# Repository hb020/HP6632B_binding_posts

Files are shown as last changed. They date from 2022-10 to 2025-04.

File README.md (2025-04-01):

HP 66332A and HP 6632B-6634B Frontpanel Binding Post PCB
===================
This repository contains the schematics for a PCB to mount frontpanel binding post on an HP 6632B (and siblings) power supply. It is an adaption of the original A4 PCB used in option #020 units.

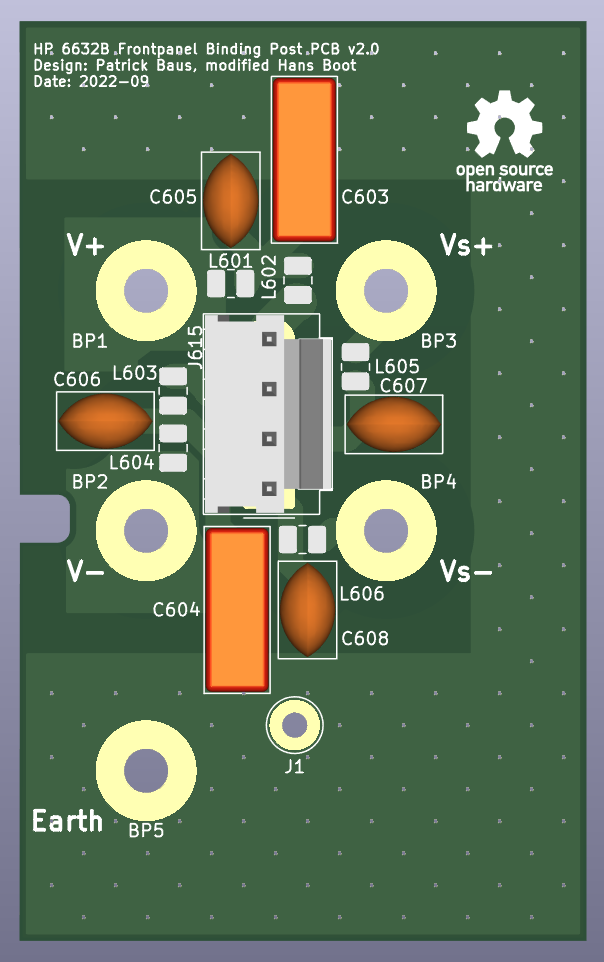
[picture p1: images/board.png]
Current driver circuit board


In contrast to the original option #20 PCB, this board breaks out the sense connections as well and also the chassis ground. This makes connecting multiple HP 663xB in parallel possible. On the downside, this requires connecting the sense pins externally.   

The components chosen allow the board to be used on all variants of the HP 663xB family - even the 100 V 6634B. A variety of different binding posts can be used. There are HP/Agilent versions available on Ebay. Examples:
- Pomona 4243-0 ([Digikey](https://www.digikey.de/en/products/detail/pomona-electronics/4243-0/604321)) and 3760-5 ([Digikey](https://www.digikey.de/en/products/detail/pomona-electronics/3760-5/736554)).
- EZ-Hook 9406 ([Digikey](https://www.digikey.fr/en/products/detail/e-z-hook/9406/574036)) (only to be found in red and black as a set or individually under the name EZ-Hook 9280BLK or 9280RED)

The final result looks like this:
HP 66332A with binding posts

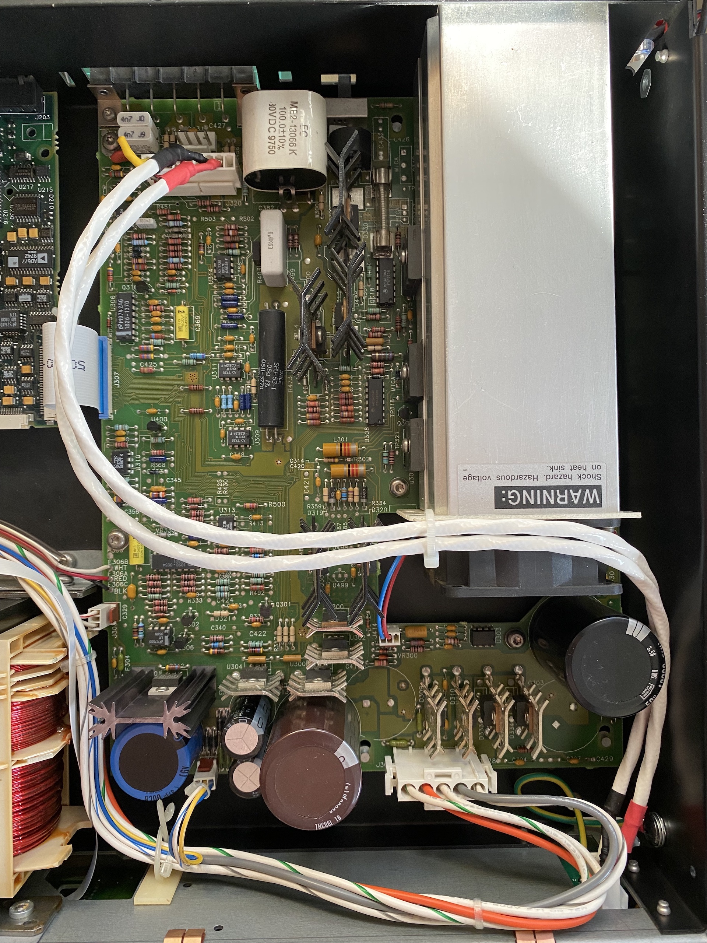
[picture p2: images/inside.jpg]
HP 66332A inside


The following changes were made to Patrick Baus's original version:

- the terminals are moved around to match a more standard layout.
- added documentation about the connectivity to the main board.
- the wire connections are moved to better align with the hole in the chassis behind the posts.
- the slot in the PCB for the front panel fixation screw is widened a bit to allow more freedom.
- newer KiCad version (6.0).
- added a FreeCAD model.
- uses a 3D printed [Front Terminal Adapter](freecad/Front_Terminal_Adapter.stl) (also see below) for more rigidity.

About
-----
The root folder contains the KiCAD files.

The gerber files can be found in the [/gerber](gerber/) folder.

A 3D model from FreeCAD can be found in the [/freecad](freecad/) folder. That model was used to determine the placement of the connector and the ground wire.

Labels for a Dymo printer can be found in the [/labels](labels/) folder.

Test scripts (via Prologix USB-GPIB) can be found in the [/testscripts](testscripts/) folder.

Related Repositories and info
-----------------------------

See the following repositories for more information

KiCAD schematic libraries: https://github.com/PatrickBaus/KiCad-libraries

A "HP 66xxA 65xxA PSU Front Panel Binding Post Adapter" plate from [NearFarMedia](https://www.thingiverse.com/thing:4299873) is recommended. It is also [included in the FreeCad file](freecad/Front_Terminal_Adapter.stl). The slots for the binding posts might be a bit tighter, but it works superbly.

I'd also recommend to look at [Barbouri's efforts](https://www.barbouri.com/2021/04/23/hewlett-packard-agilent-6632b-upgrade/) for his upgrade.

You may want to combine this with the [option 760 relay board](https://github.com/hb020/HP6632B_relay_board).

License
-------

This work is released under the Cern OHL v.1.2
See www.ohwr.org/licenses/cern-ohl/v1.2 or the included LICENSE file for more information.

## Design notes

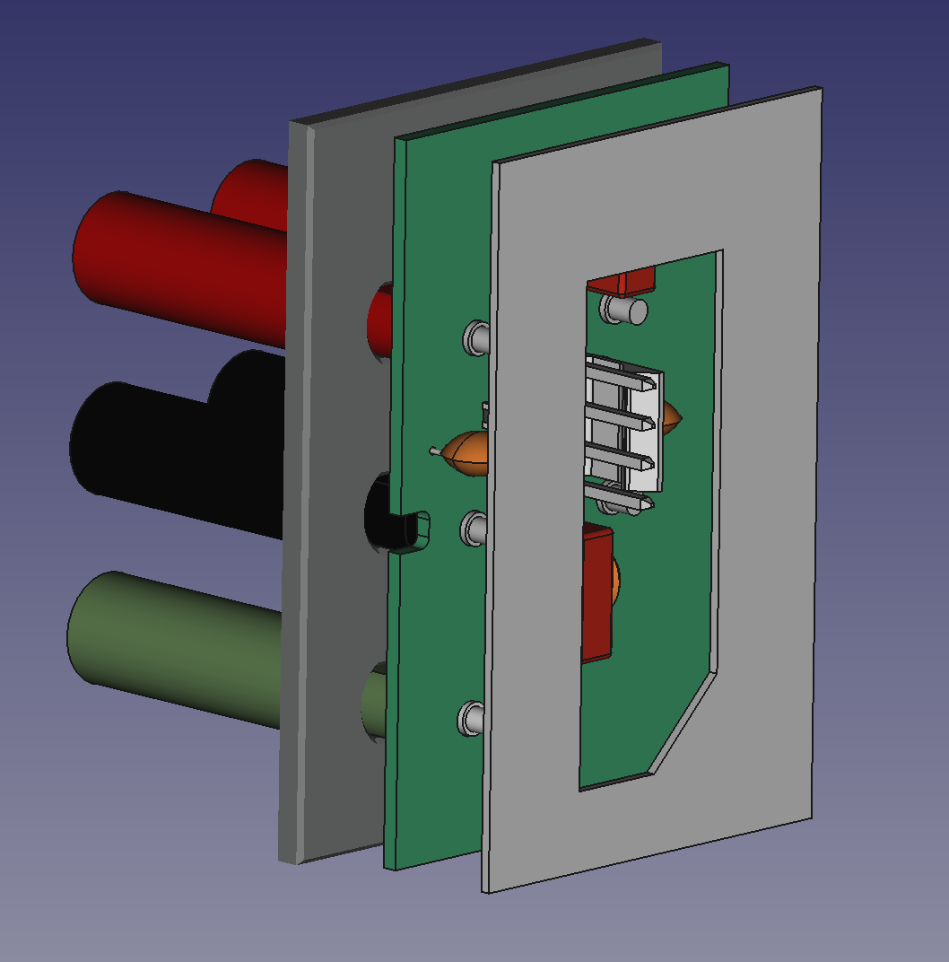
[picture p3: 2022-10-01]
images/3d.png

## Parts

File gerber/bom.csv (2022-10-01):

Designator | Footprint | Quantity | Value | LCSC Part #
BP1, BP2, BP3, BP4, BP5 | MountingHole_3.5mm_Pad | 5 | Conn_01x01
C603, C604 | C_Rect_L13.0mm_W5.0mm_P10.00mm_FKS3_FKP3_MKS4 | 2 | 4.7n
C605, C606, C607, C608 | C_Disc_D7.5mm_W4.4mm_P5.00mm | 4 | 220p
J1 | TestPoint_THTPad_D4.0mm_Drill2.0mm | 1 | Conn_01x01
J615 | Molex_KK-396_A-41791-0004_1x04_P3.96mm_Vertical | 1 | Conn_01x04_Male
L601, L602, L603, L604, L605, L606 | L_1008_2520Metric_Pad1.43x2.20mm_HandSolder | 6 | 150n
LOGO1 | OSHW-Logo_7.5x8mm_SilkScreen | 1 | Logo_Open_Hardware_Small

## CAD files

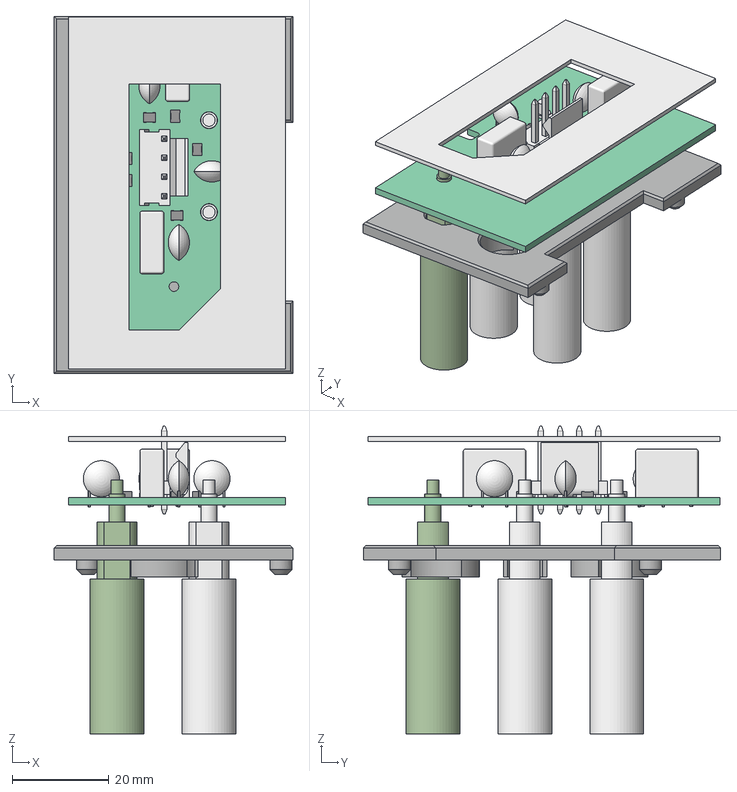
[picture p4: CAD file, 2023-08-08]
freecad/combined.FCStd
49.5 x 74.0 x 63.8 mm
9280_GND
Pcb_361c
C604_C_Rect_L130mm_W50mm_P1000mm_FKS3_FKP3_MKS4_00005f239962
C605_C_Disc_D75mm_W44mm_P500mm_00005f239977
L601_L_1008_2520Metric_00005f2399cf
L603_L_1008_2520Metric_00005f2399f1
L606_L_1008_2520Metric_00005f23d51d
C607_C_Disc_D75mm_W44mm_P500mm_00005f23e080
C608_C_Disc_D75mm_W44mm_P500mm_00005f23e095
L602_L_1008_2520Metric_00005f241a9f
L604_L_1008_2520Metric_00005f2428f3
L605_L_1008_2520Metric_00005f242ef0
C603_C_Rect_L130mm_W50mm_P1000mm_FKS3_FKP3_MKS4_00005f247355
J615_1_00005f3145fd[2]
C606_C_Disc_D75mm_W44mm_P500mm_00005f315ffa
Back_metal_cutout
Front_Terminal_Adapter

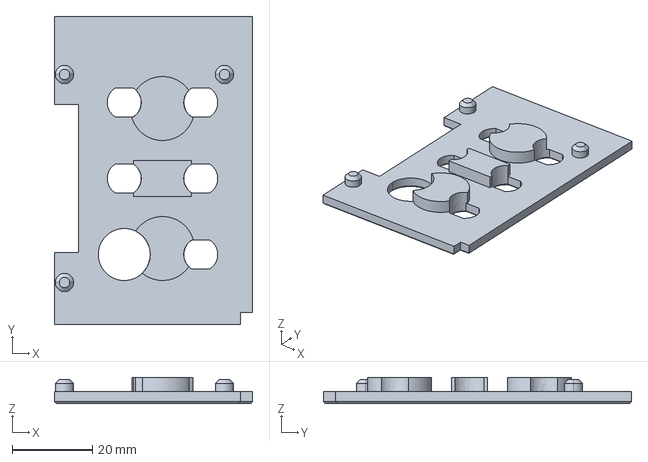
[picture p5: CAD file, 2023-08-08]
freecad/Front_Terminal_Adapter.stp
49.5 x 77.0 x 6.50 mm

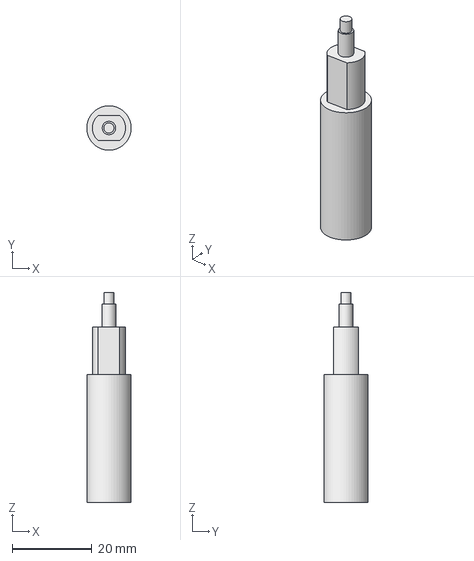
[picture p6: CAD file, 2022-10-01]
freecad/ezhook_9280RED.FCStd
11.1 x 11.2 x 52.6 mm

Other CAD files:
freecad/ezhook_9280BLK.FCStd
freecad/Front_Terminal_Adapter.stl

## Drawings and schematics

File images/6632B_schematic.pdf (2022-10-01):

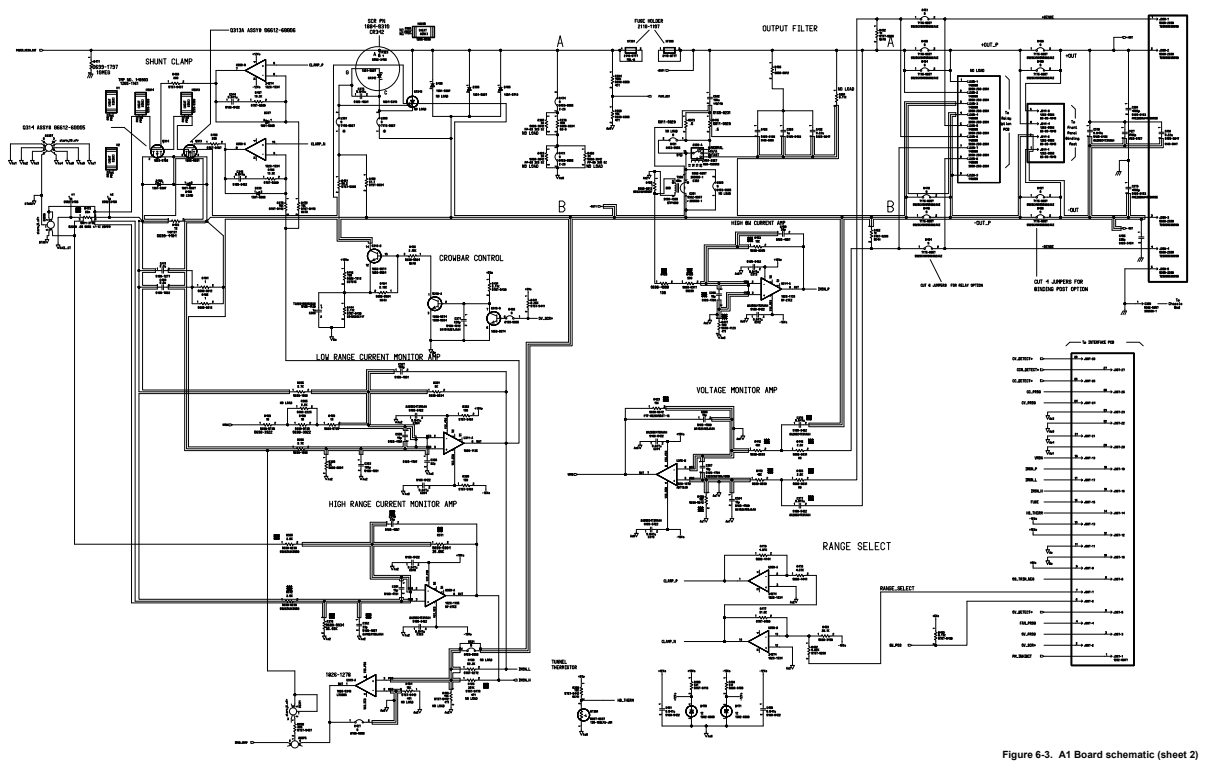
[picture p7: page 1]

Figure 6-3. A1 Board schematic (sheet 2)

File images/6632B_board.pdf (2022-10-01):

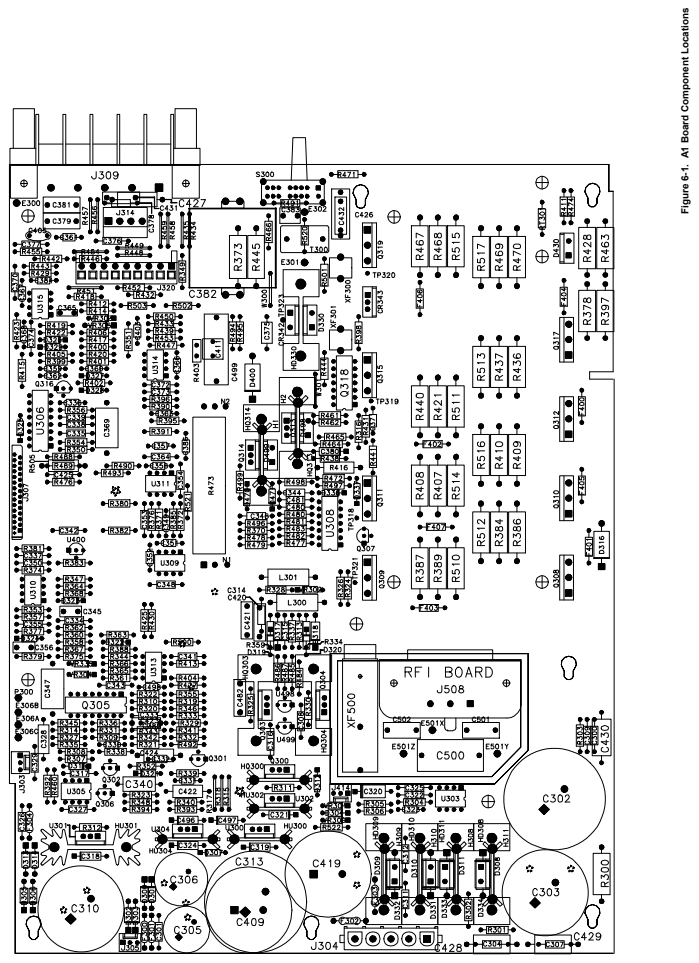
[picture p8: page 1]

Figure 6-1. A1 Board Component Locations

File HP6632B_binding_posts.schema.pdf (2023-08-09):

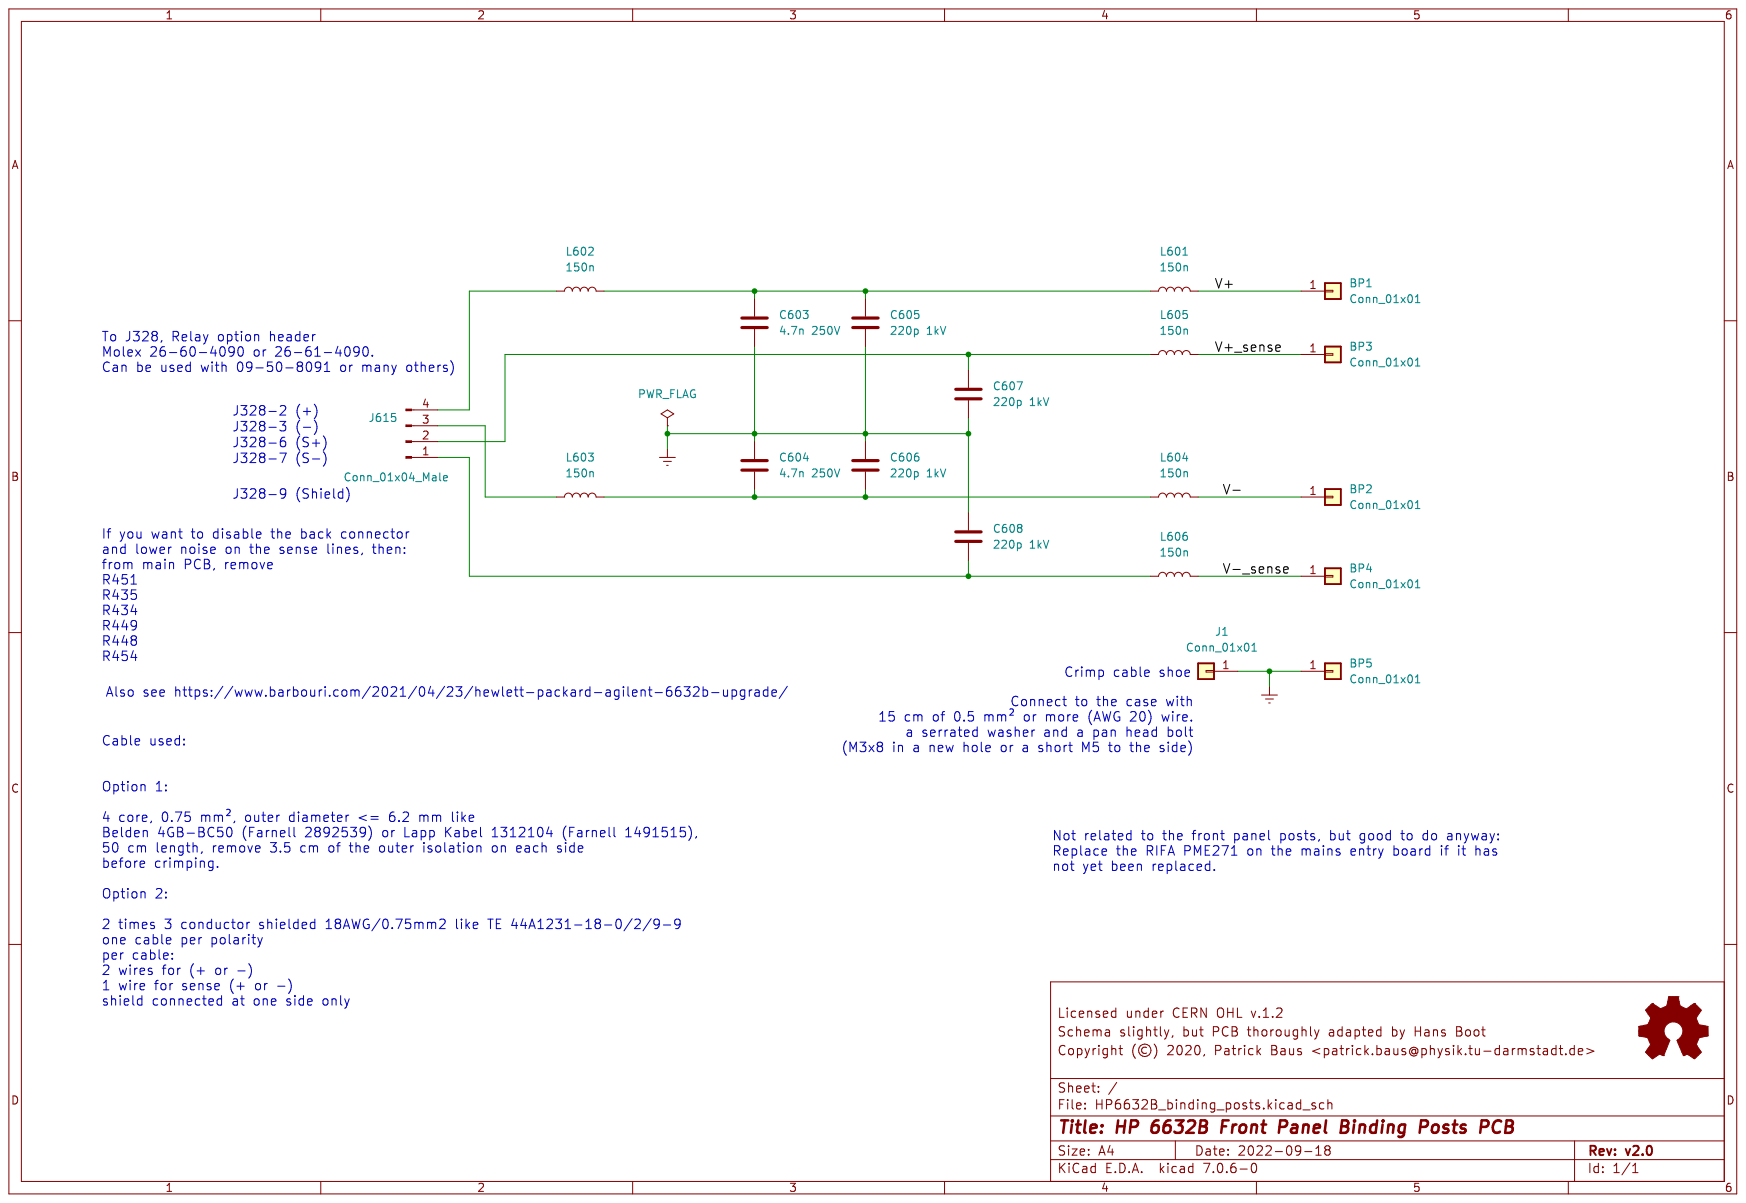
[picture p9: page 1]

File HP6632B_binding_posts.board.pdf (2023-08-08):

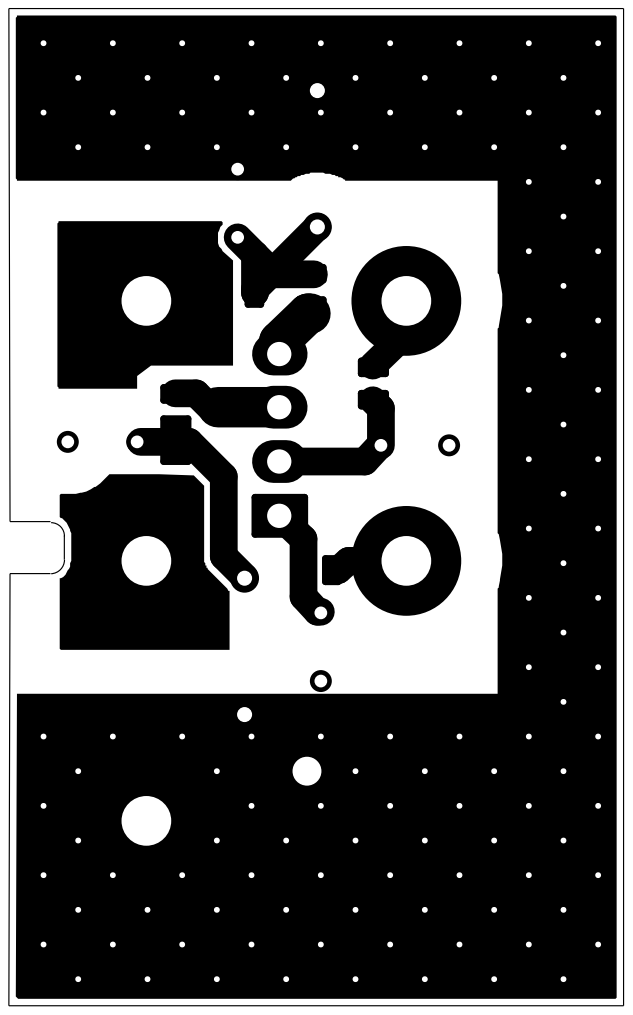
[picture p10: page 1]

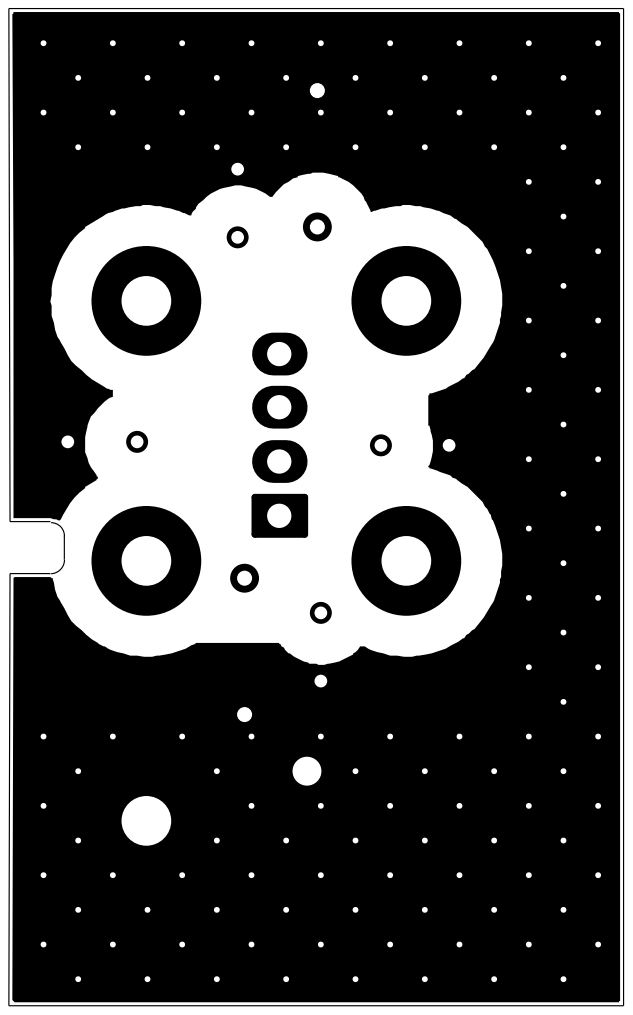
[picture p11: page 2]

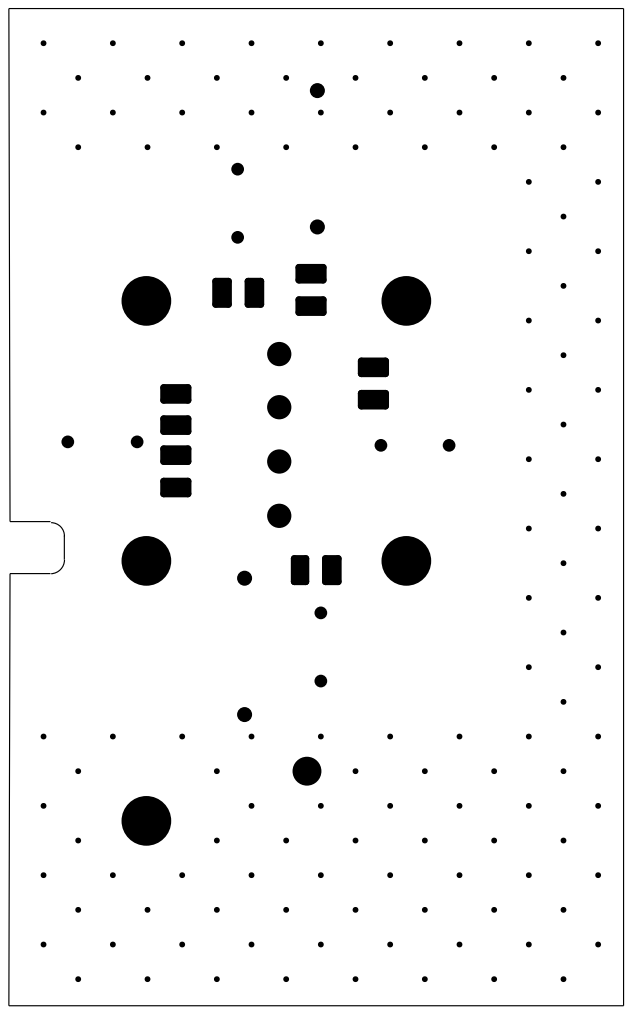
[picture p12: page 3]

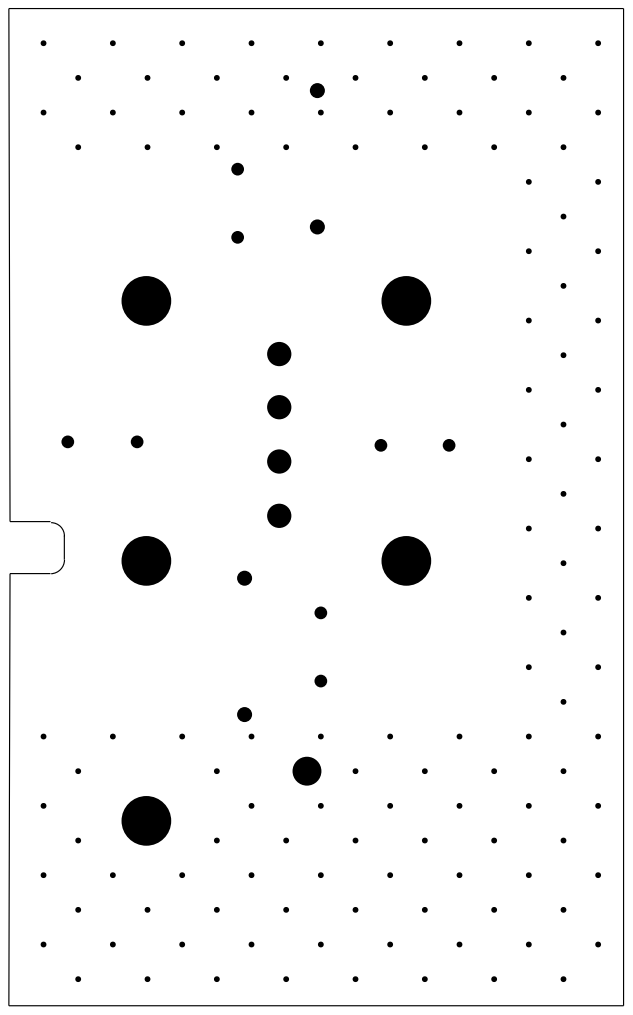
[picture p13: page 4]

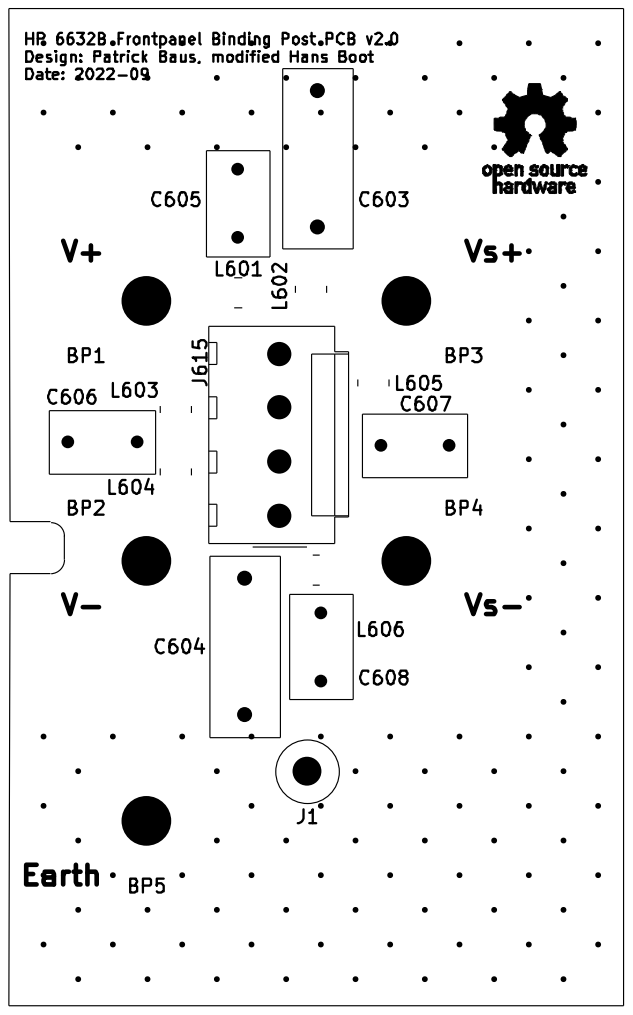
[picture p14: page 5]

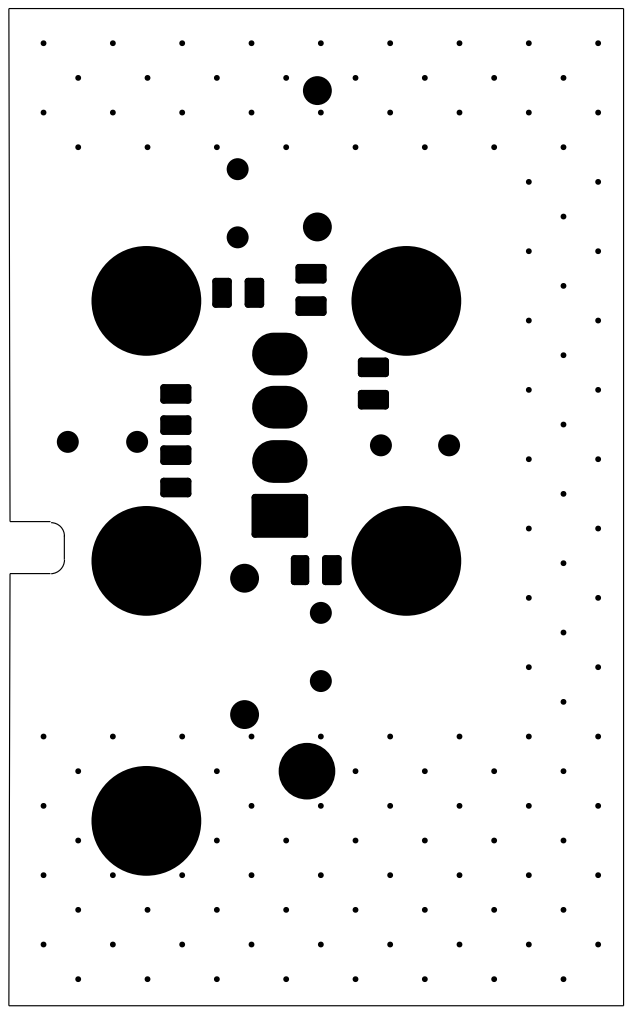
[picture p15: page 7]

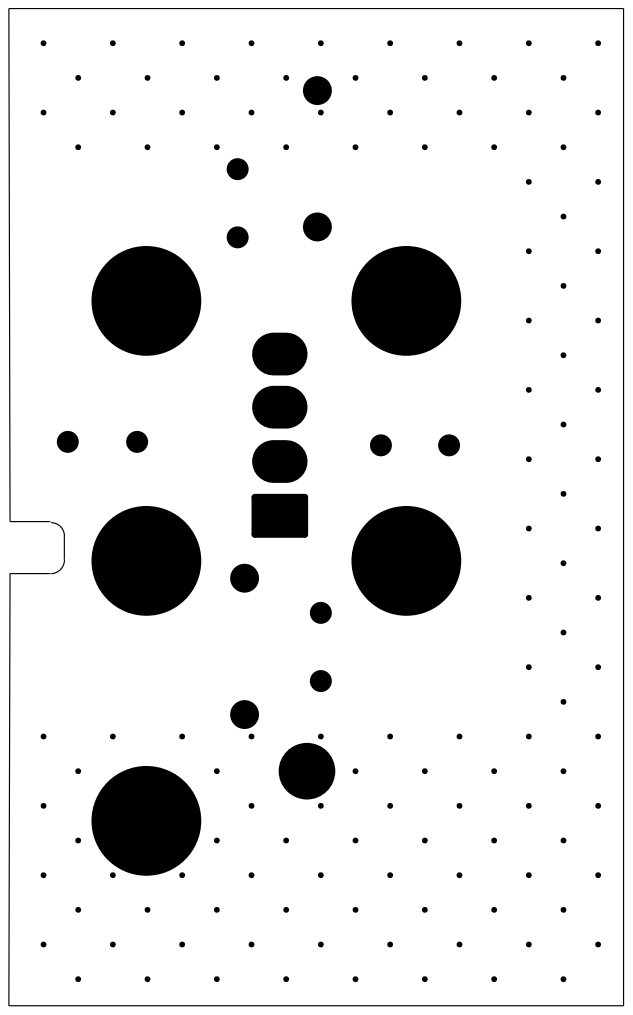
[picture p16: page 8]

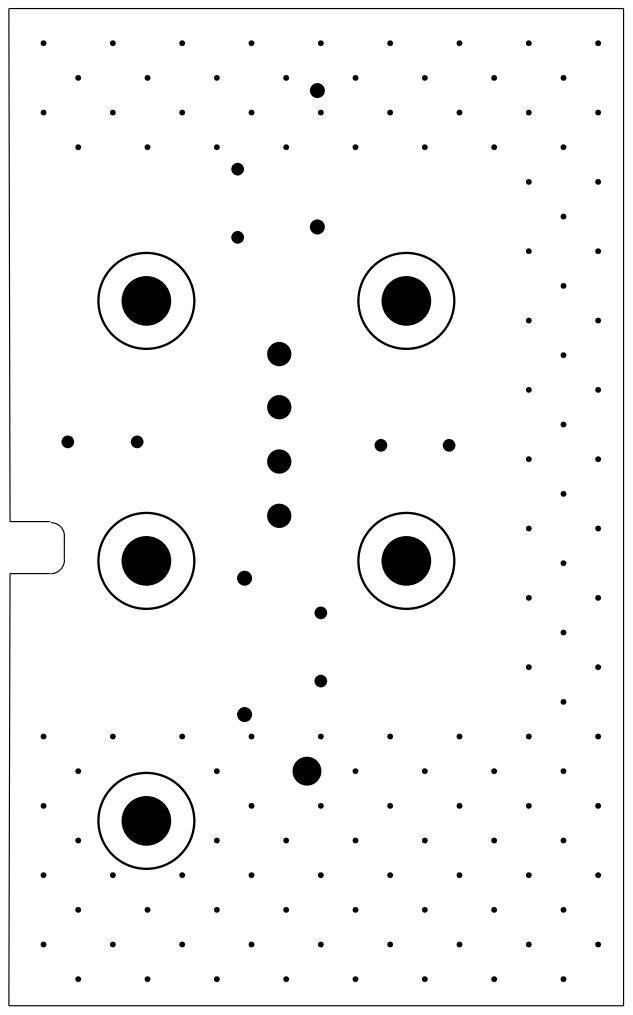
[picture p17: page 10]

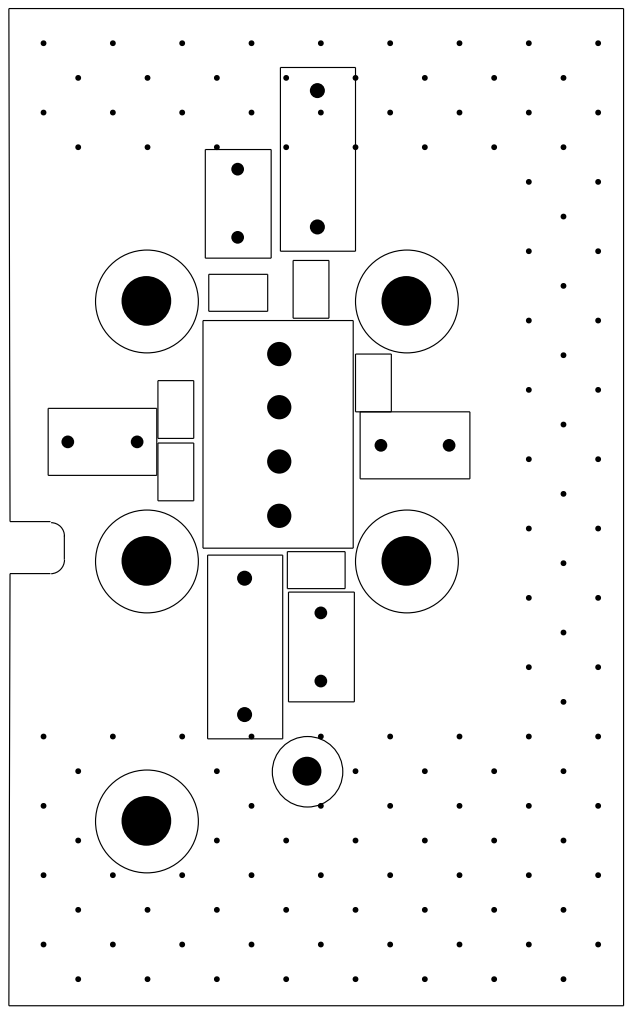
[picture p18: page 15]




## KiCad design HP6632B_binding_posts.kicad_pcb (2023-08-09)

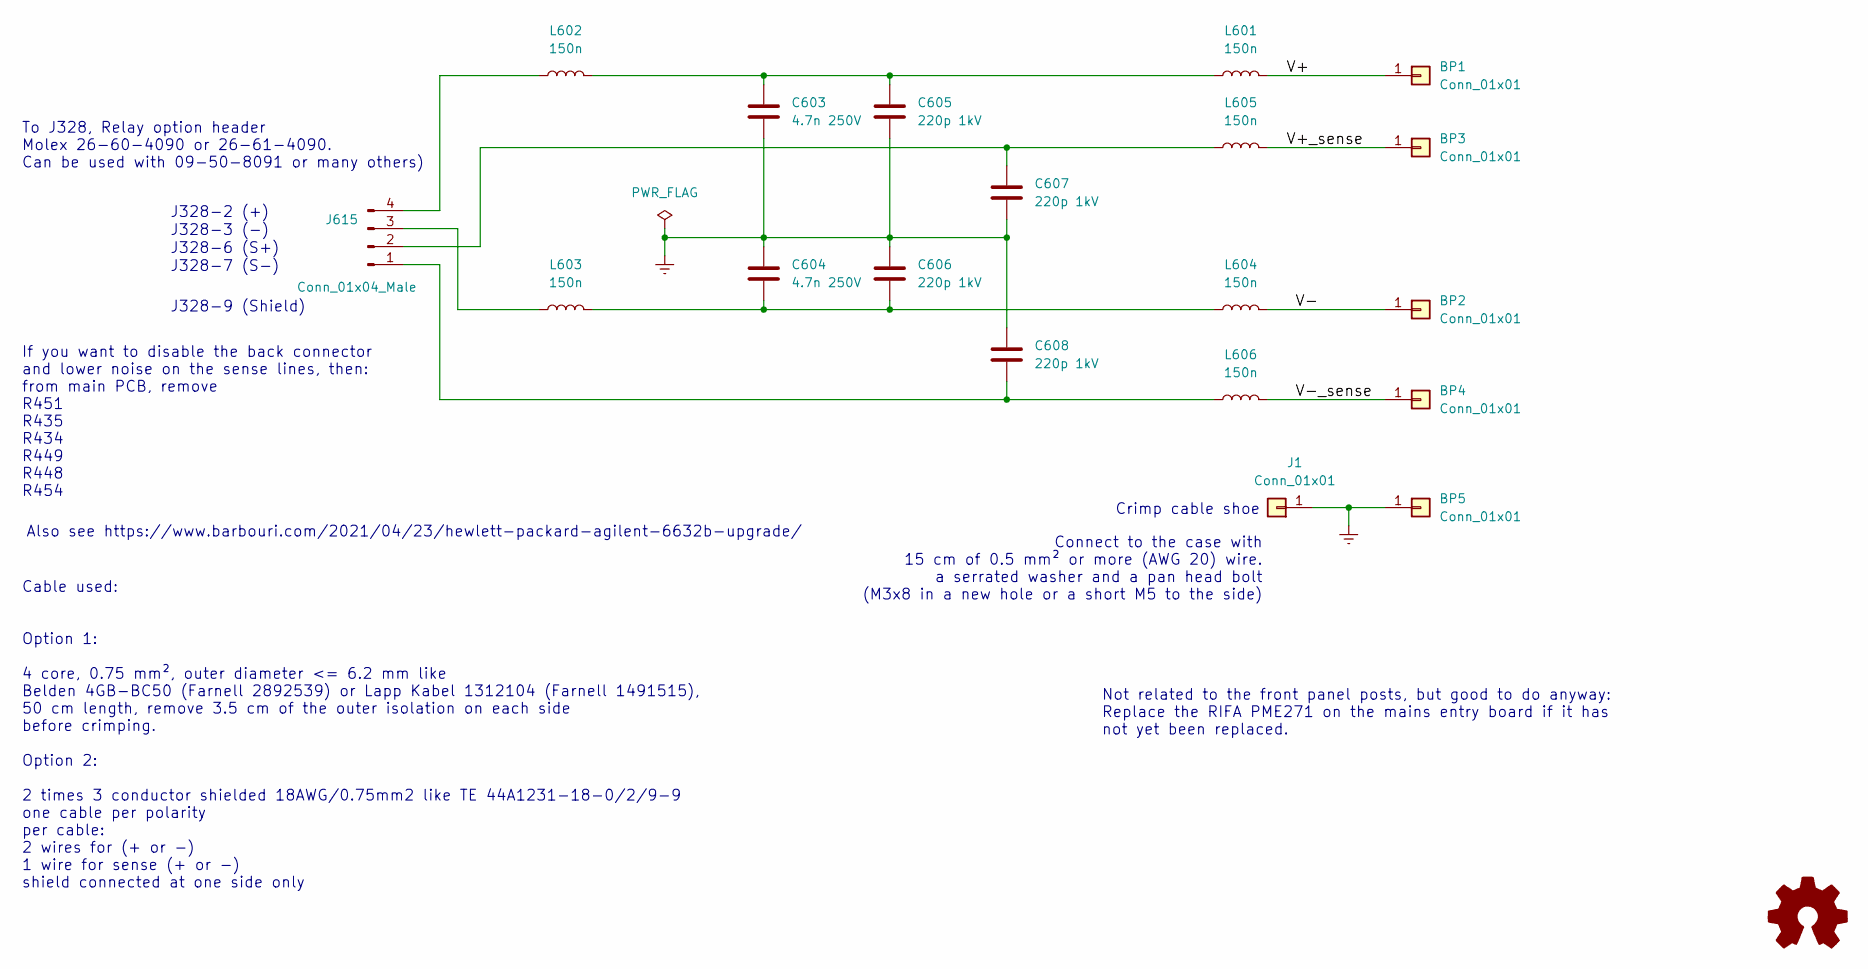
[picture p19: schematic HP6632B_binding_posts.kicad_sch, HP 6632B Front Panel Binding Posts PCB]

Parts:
BP1, BP2, BP3, BP4, BP5: Conn_01x01; MountingHole_3.5mm_Pad
C603, C604: 4.7n 250V; C_Rect_L13.0mm_W5.0mm_P10.00mm_FKS3_FKP3_MKS4
C605, C606, C607, C608: 220p 1kV; C_Disc_D7.5mm_W4.4mm_P5.00mm
J1: Conn_01x01; TestPoint_THTPad_D4.0mm_Drill2.0mm
J615: Conn_01x04_Male; Molex_KK-396_A-41791-0004_1x04_P3.96mm_Vertical
L601, L602, L603, L604, L605, L606: 150n; L_1008_2520Metric_Pad1.43x2.20mm_HandSolder
LOGO1: Logo_Open_Hardware_Small; OSHW-Logo_7.5x8mm_SilkScreen

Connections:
/V+: BP1.1, L601.2
/V+_sense: BP3.1, L605.2
/V-: BP2.1, L604.2
/V-_sense: BP4.1, L606.2
Earth: BP5.1, C603.2, C604.1, C605.2, C606.1, C607.2, C608.1, J1.1
unnamed: C603.1, C605.1, L601.1, L602.2
unnamed: C604.2, C606.2, L603.2, L604.1
unnamed: C608.2, J615.1, L606.1
unnamed: C607.1, J615.2, L605.1
unnamed: J615.3, L603.1
unnamed: J615.4, L602.1

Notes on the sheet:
J328-6 (S+)
J328-2 (+)
Connect to the case with 15 cm of 0.5 mm² or more (AWG 20) wire. a serrated washer and a pan head bolt (M3x8 in a new hole or a short M5 to the side)
J328-3 (-)
J328-7 (S-)
To J328, Relay option header Molex 26-60-4090 or 26-61-4090. Can be used with 09-50-8091 or many others)
Cable used: Option 1: 4 core, 0.75 mm², outer diameter <= 6.2 mm like Belden 4GB-BC50 (Farnell 2892539) or Lapp Kabel 1312104 (Farnell 1491515), 50 cm length, remove 3.5 cm of the outer isolation on each side before crimping. Option 2: 2 times 3 conductor shielded 18AWG/0.75mm2 like TE 44A1231-18-0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
Crimp cable shoe
Also see https://www.barbouri.com/2021/04/23/hewlett-packard-agilent-6632b-upgrade/
Not related to the front panel posts, but good to do anyway: Replace the RIFA PME271 on the mains entry board if it has not yet been replaced.
J328-9 (Shield)
If you want to disable the back connector and lower noise on the sense lines, then: from main PCB, remove R451 R435 R434 R449 R448 R454

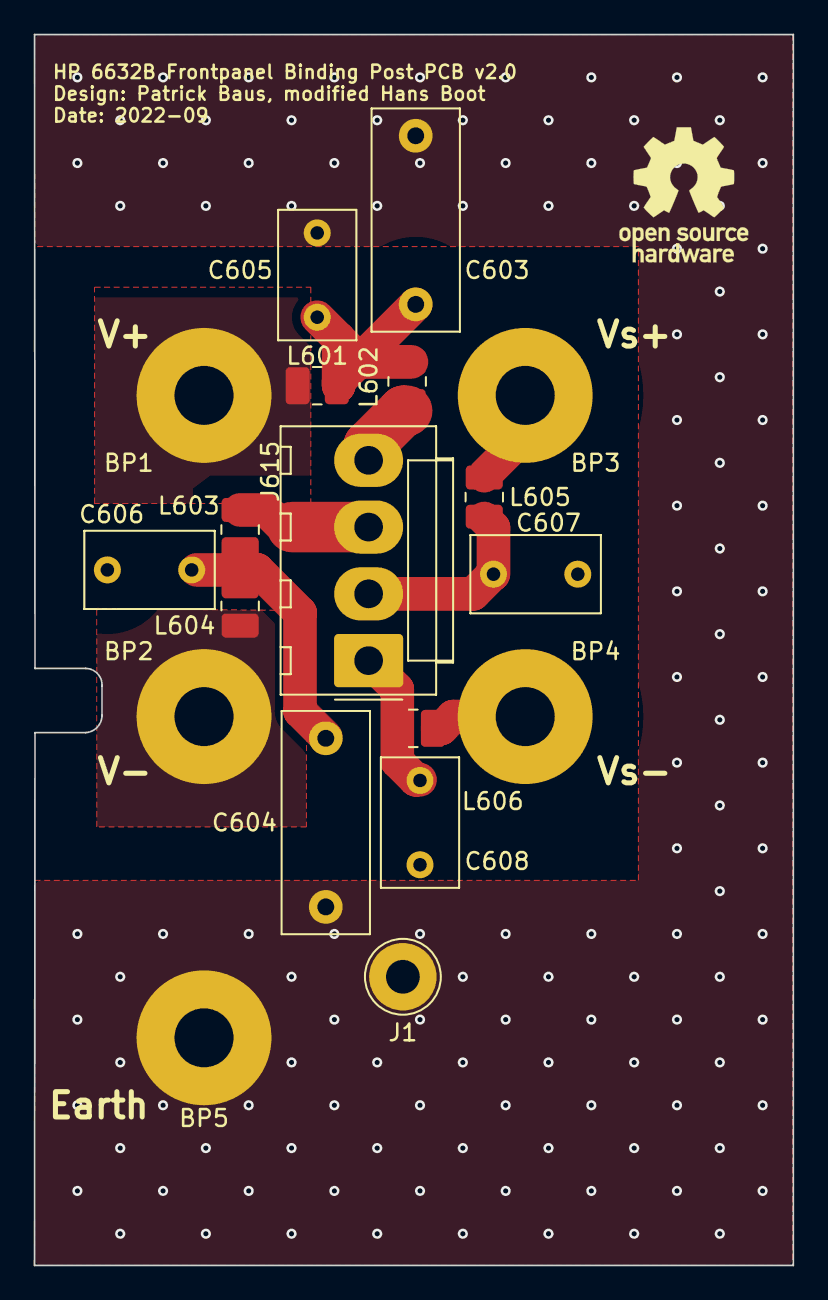
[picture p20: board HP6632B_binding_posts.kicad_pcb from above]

Board: 2 copper layers, 45.0 x 73.0 mm, 20 parts (0 on the bottom side), 11 nets.

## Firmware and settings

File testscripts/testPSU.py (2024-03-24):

import time
import sys
import glob
import serial

# the global vars of the devices
ser = serial.Serial()

DEBUG = False

# SCPI Addresses:
# Current source: USB, prologix USB-GPIB. Hence: not via pyvisa, as that is not stable for that adapter.
ADDR_SOURCE_DEFAULT = "/dev/cu.usbmodem11101"
AUTOREAD = False
# serial timeout: 20ms minimum
SERIAL_TIMEOUT = 0.02
HAS_OPT760 = True


def serial_ports():
    """ Lists serial port names

        :raises EnvironmentError:
            On unsupported or unknown platforms
        :returns:
            A list of the serial ports available on the system
    """
    if sys.platform.startswith('win'):
        ports = ['COM%s' % (i + 1) for i in range(256)]
    elif sys.platform.startswith('linux') or sys.platform.startswith('cygwin'):
        # this excludes your current terminal "/dev/tty"
        ports = glob.glob('/dev/cu[A-Za-z]*')
    elif sys.platform.startswith('darwin'):
        ports = glob.glob('/dev/cu.usbmodem*')
    else:
        raise EnvironmentError('Unsupported platform')

    result = []
    for port in ports:
        try:
            s = serial.Serial(port)
            s.close()
            result.append(port)
        except (OSError, serial.SerialException):
            pass
    return result


def sendSerialCmdRaw(cmd):
    bcmd = bytearray()
    bcmd.extend(cmd.encode("ascii"))
    bcmd.append(0x0D)  # CR
    bcmd.append(0x0A)  # LF
    ser.write(bcmd)


def sendSerialCmd(cmd, readReply=True, delaysecs=0):
    global ser
    if DEBUG:
        if not readReply:
            print(f"Sending: {cmd}")
        else:
            print(f"Sending: {cmd} : ", end="")
    sendSerialCmdRaw(cmd)
    if readReply:
        if delaysecs > 0:
            time.sleep(delaysecs)
        if not AUTOREAD:
            sendSerialCmdRaw("++read eoi")
        s = ser.read(256)
        retstr = s.decode("ascii")
        if DEBUG:
            print(f"{retstr} ({len(s)}b)")
        return retstr
    else:
        s = ser.read(256)
        return None


def inst_cs_query(cmd):
    delaysecs = 0
    if cmd.startswith("MEAS"):
        # 40msec minimum
        delaysecs = 0.05
    return sendSerialCmd(cmd, True, delaysecs)


def inst_cs_write(cmd):
    return sendSerialCmd(cmd, False)


def inst_cs_init_serial():
    global ser

    port = None
    baudrate = 38400  # 115200
    
    ports = serial_ports()
    if len(ports) == 0:
        print('ERROR: No serial ports found')
        return False

    if (len(ports) > 1):
        if ADDR_SOURCE_DEFAULT in ports:
            port = ADDR_SOURCE_DEFAULT
        else:
            print(f'ERROR: Found multiple ports, and the default port is not in it. Found {ports}. Select the port.')
            return False
    
    if len(ports) == 1:
        port = ports[0]

    print(f"Using Prologix device on port \"{port}\".")
    ser = serial.Serial(port, baudrate=baudrate, timeout=SERIAL_TIMEOUT)

    # using a fenrir GPIB-USB clone. Manual: https://github.com/fenrir-naru/gpib-usbcdc/blob/master/docs/manual_by_Alessandro.pdf
    sendSerialCmd("++mode 1", False)  # controller mode (the only mode it supports)
    if AUTOREAD:
        sendSerialCmd("++auto 1", False)  # no need for "++read eoi"
    else:
        sendSerialCmd("++auto 0", False)  # need for "++read eoi"
    sendSerialCmd("++eos 0", False)  # CR/LF is oes
    sendSerialCmd("++read", False)  # read all data until timeout. fenrir FW specific.
    return True


def inst_cs_init_device(addr):
    
    sendSerialCmd("++addr " + str(addr))
    
    inst_cs_write("*CLS")
    # check ID
    s = inst_cs_query("*IDN?").strip()
    if len(s) > 0:
        print(f"Device {addr} = {s}")
        if ("6631B" not in s) and ("6632B" not in s) and ("66332A" not in s) and ("6633B" not in s) and ("6634B" not in s):
            print(f'ERROR: device ID is unexpected: "{s}"')
            return False
    else:
        print(f"Device {addr} is absent")
        return False

    # output off, voltage 0V, current 0
    inst_cs_write("OUTP 0")
    if HAS_OPT760:
        inst_cs_write("OUTP:REL:POL NORM")
    inst_cs_write("SOUR:VOLT 0")
    inst_cs_write("SOUR:CURR 0")
    s = inst_cs_query("SYST:ERR?").strip()
    if not s.startswith("+0"):
        print(f'ERROR during init_device({addr}): "{s}"')
        return False

    return True


def getMaxVolts():
    s = inst_cs_query("*IDN?").strip()
    if "6631B" in s:
        return 9.190
    if ("6632B" in s) or ("66332A" in s):
        return 20.475
    if "6633B" in s:
        return 51.188
    if "6634B" in s:
        return 102.38
    return 0


def getMinVolts():
    if HAS_OPT760:
        return -1 * getMaxVolts()
    else:
        return 0


def getMaxAmps():
    s = inst_cs_query("*IDN?").strip()
    if "6631B" in s:
        return 10.237
    if ("6632B" in s) or ("66332A" in s):
        return 5.1188
    if "6633B" in s:
        return 2.0475
    if "6634B" in s:
        return 1.0238
    return 0


def getMinAmps():
    if HAS_OPT760:
        return -1 * getMaxAmps()
    else:
        return 0


def inst_cs_close():
    inst_cs_write("OUTP 0")
    if HAS_OPT760:
        inst_cs_write("OUTP:REL:POL NORM")
    inst_cs_write("SOUR:VOLT 0")
    inst_cs_write("SOUR:CURR 0")
    

def initMeasurements():
    inst_cs_write("OUTP 1")
    # in case you shorted, let CC mode activate
    time.sleep(1)
    

def closeMeasurements():
    inst_cs_close()


# sets the current, and lets the PSU settle some time. This PSU has a tendency to take time to go to CC mode.
def setVoltage(val, oldval=None):
    bNegative = False
    sleeptime_s = 0.5 # the time between set voltage and measure
    setval = abs(val)
    if val < 0:
        bNegative = True
        if oldval is None or oldval >= 0:
            # avoid glitches, set output to 0, then reverse polarity
            inst_cs_write("SOUR:VOLT 0")
            inst_cs_write("OUTP:REL:POL REV")
            sleeptime_s += 0.4
    else:
        if oldval is None or oldval < 0:
            # avoid glitches, set output to 0, then reverse polarity
            inst_cs_write("SOUR:VOLT 0")
            inst_cs_write("OUTP:REL:POL NORM")
            sleeptime_s += 0.4

    inst_cs_write(f"SOUR:VOLT {setval:.5f}")
    s = inst_cs_query("SYST:ERR?").strip()
    if not s.startswith("+0"):
        print(f'ERROR during setVoltage({val}): "{s}"')
        return False
    s = inst_cs_query("*OPC?").strip()
    s = inst_cs_query("SYST:ERR?").strip()
    if not s.startswith("+0"):
        print(f'ERROR during setVoltage({val}) OPC: "{s}"')
        return False
    # print(f"setVoltage({val}) OPC={s}")    

    # now measure
    # wait the time requested by measurement plus the relay switchover
    if sleeptime_s > 0:      
        time.sleep(sleeptime_s)
        sleeptime_s = 0
    v = inst_cs_query("MEAS:VOLT?").strip()
    s = inst_cs_query("SYST:ERR?").strip()
    if not s.startswith("+0"):
        print(f'ERROR during setVoltage({val}) readback: "{s}"')
        return False
    try:
        f = float(v)
    except:
        print(f'ERROR during setVoltage({val}) readback: "{v}", not a float')
        return False   
    if bNegative:
        f = f * -1
    print(f"Set V={val:.3f}, Measured V={f:.3f}, offset={(f-val):.3f}")
    return True


def setCurrent(val, oldval=None):
    sleeptime_s = 0.1
    if val < 0:
        if oldval is None or oldval >= 0:
            inst_cs_write("OUTP:REL:POL REV")
            sleeptime_s += 0.4
        val = abs(val)
    else:
        if oldval is None or oldval < 0:
            inst_cs_write("OUTP:REL:POL NORM")
            sleeptime_s += 0.4

    inst_cs_write(f"SOUR:CURR {val:.5f}")
    time.sleep(sleeptime_s)


def readDevices(test):
    global inst_cm
    global inst_target

    print("Opening PSU.")
    if not inst_cs_init_serial():
        return 1
    
    for addr in range(1, 5):
        if inst_cs_init_device(addr):
            print(f"Device {addr}: initialized.")

            initMeasurements()
            maxv = getMaxVolts()
            minv = getMinVolts()
            stepv = (maxv - minv) / 20
            if stepv < 1:
                stepv = 1
            
            print("Looping through voltages:")
            oldv = None
            v = minv
            while v <= maxv:
                if not setVoltage(v, oldv):
                    break
                oldv = v
                v += stepv
            print("Closing")
            closeMeasurements()


if __name__ == "__main__":
    # set param to True to force a short test
    readDevices(False)

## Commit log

2020-10-23 Updated to v1.1 Moved cutout 1.5 mm down Decreased size of earth connection J1
    [main-B_Cu.gbr, main-B_Fab.gbr, main-B_Mask.gbr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]
2020-10-23 Added readme Added binding posts to the BOM
    [main.kicad_pcb, main.sch]
2020-10-23 Added BOM and costs file
    [cost.xlsx, main.sch, main_bom_v1.1.csv]
2020-10-23 Added missing crimp connector
    [cost.xlsx, main.sch, main_bom_v1.1.csv]
2021-07-02 Increased GND plane clearance to 0.25 mm
    [main-B_Cu.gbr, main-B_Fab.gbr, main-B_Mask.gbr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]
2022-10-01 my updates
    [HP6632B_binding_posts-B_Cu.gbr, HP6632B_binding_posts-B_Mask.gbr, HP6632B_binding_posts-B_Paste.gbr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]
2023-08-08 added 3d models of plate
    [Front_Terminal_Adapter.stl, Front_Terminal_Adapter.stp, combined.FCStd]
2023-08-08 update to newer kicad version, added interactive BOM
    [HP6632B_binding_posts.kicad_pcb, HP6632B_binding_posts.kicad_sch]
2023-08-09 better doc
    [HP6632B_binding_posts.kicad_pcb, HP6632B_binding_posts.kicad_sch]
2024-03-24 remove some glitches in the test script
    [testPSU.py]

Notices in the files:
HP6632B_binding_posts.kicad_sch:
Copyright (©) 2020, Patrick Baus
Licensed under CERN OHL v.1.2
